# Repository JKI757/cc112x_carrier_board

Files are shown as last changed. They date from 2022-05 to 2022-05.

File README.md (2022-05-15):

## About the Project

- This project is a simple PCB for a carrier board for a a Texas Instruments [CC112X EMK](https://www.ti.com/tool/CC1120EMK-420-470) development board and an STM32 Black Pill board, interface between the two, and jumper set to jump out the STM32 and attach an external microcontroller if necessary.

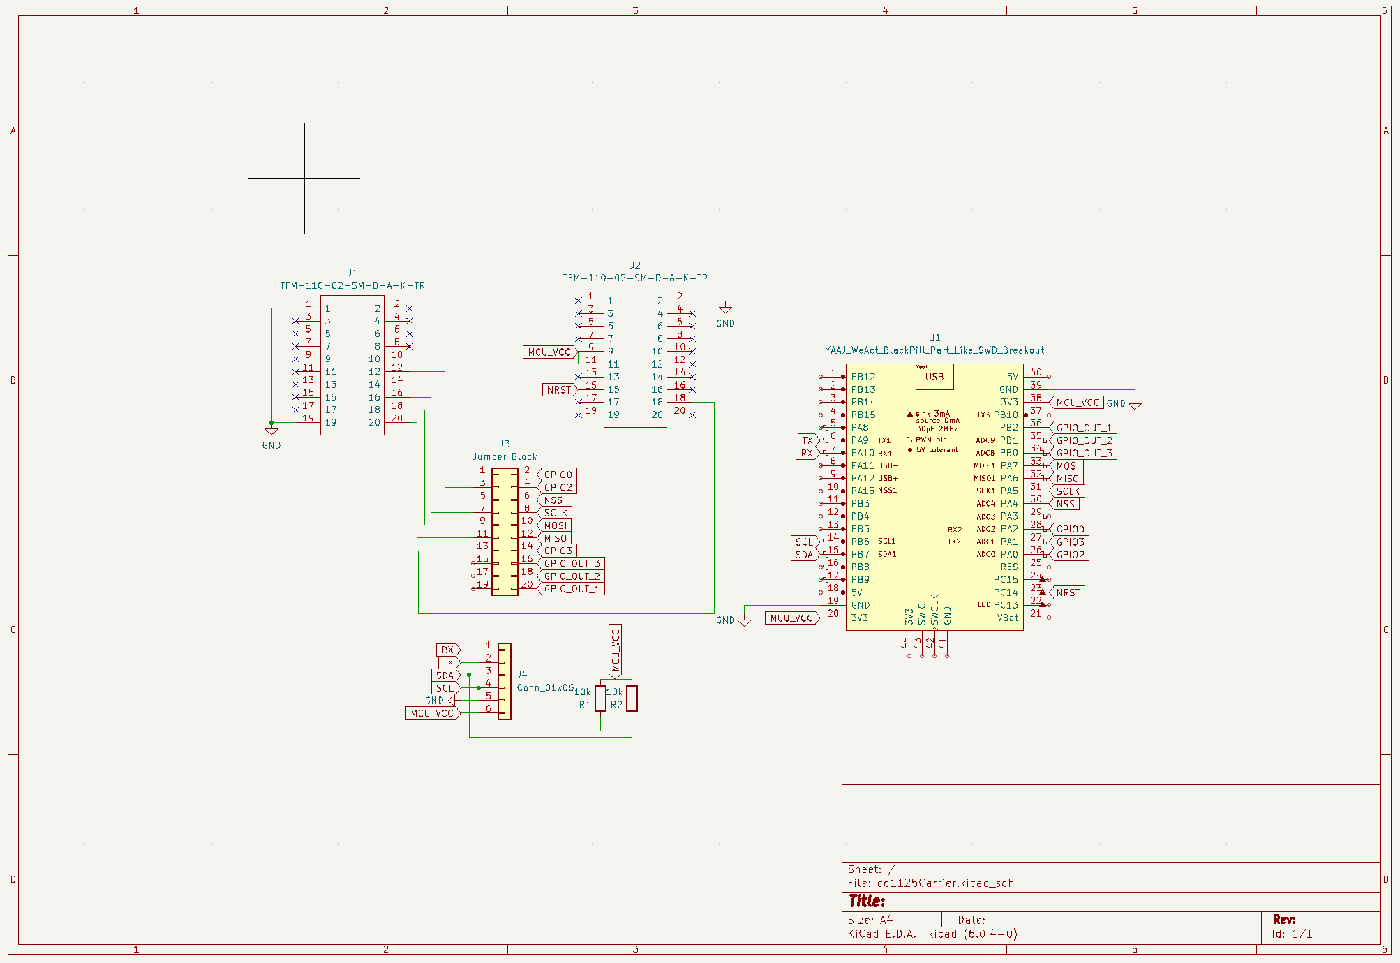
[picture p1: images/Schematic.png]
Schematic


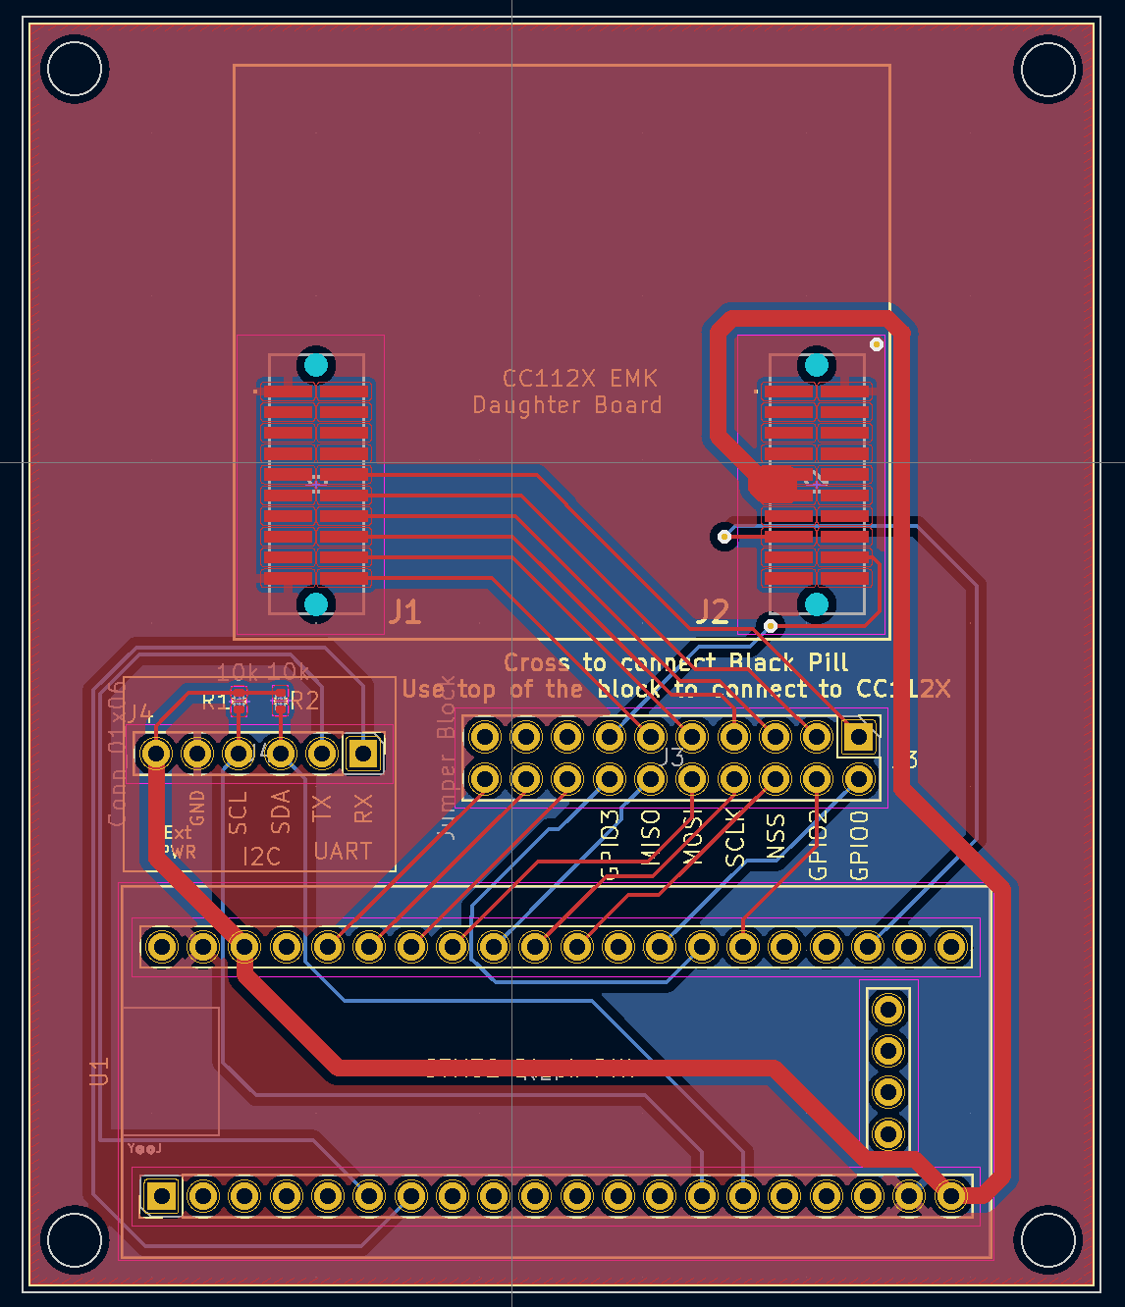
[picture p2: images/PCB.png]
PCB


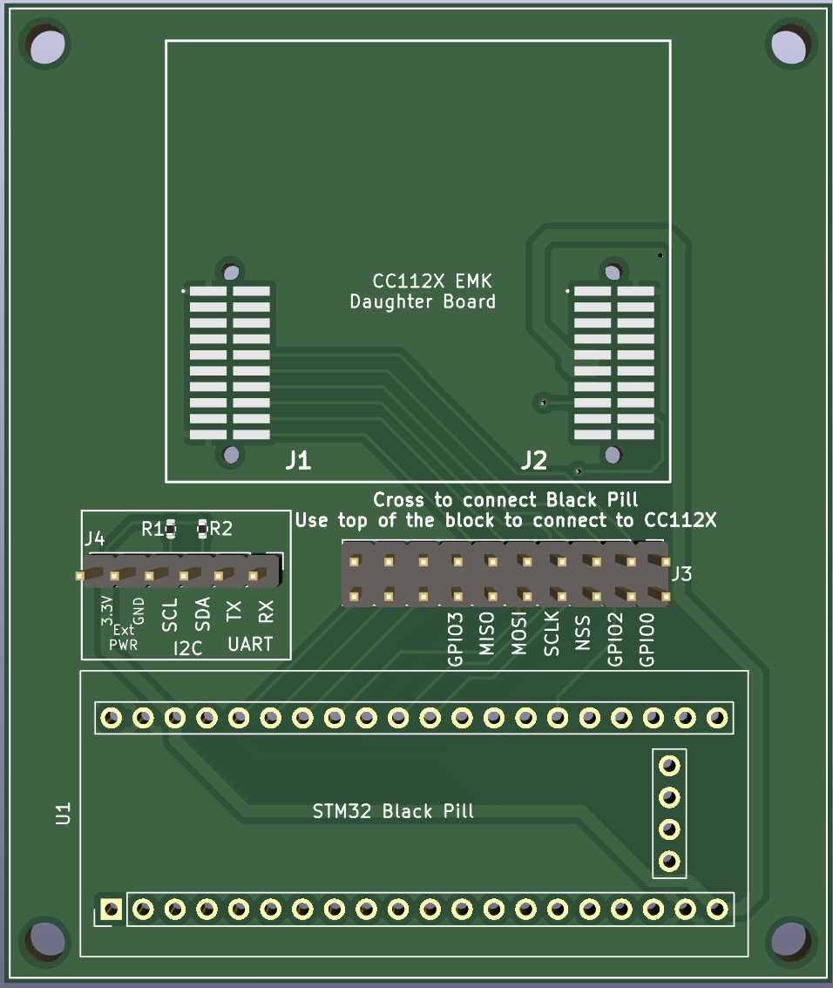
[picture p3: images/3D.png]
3D 3D View


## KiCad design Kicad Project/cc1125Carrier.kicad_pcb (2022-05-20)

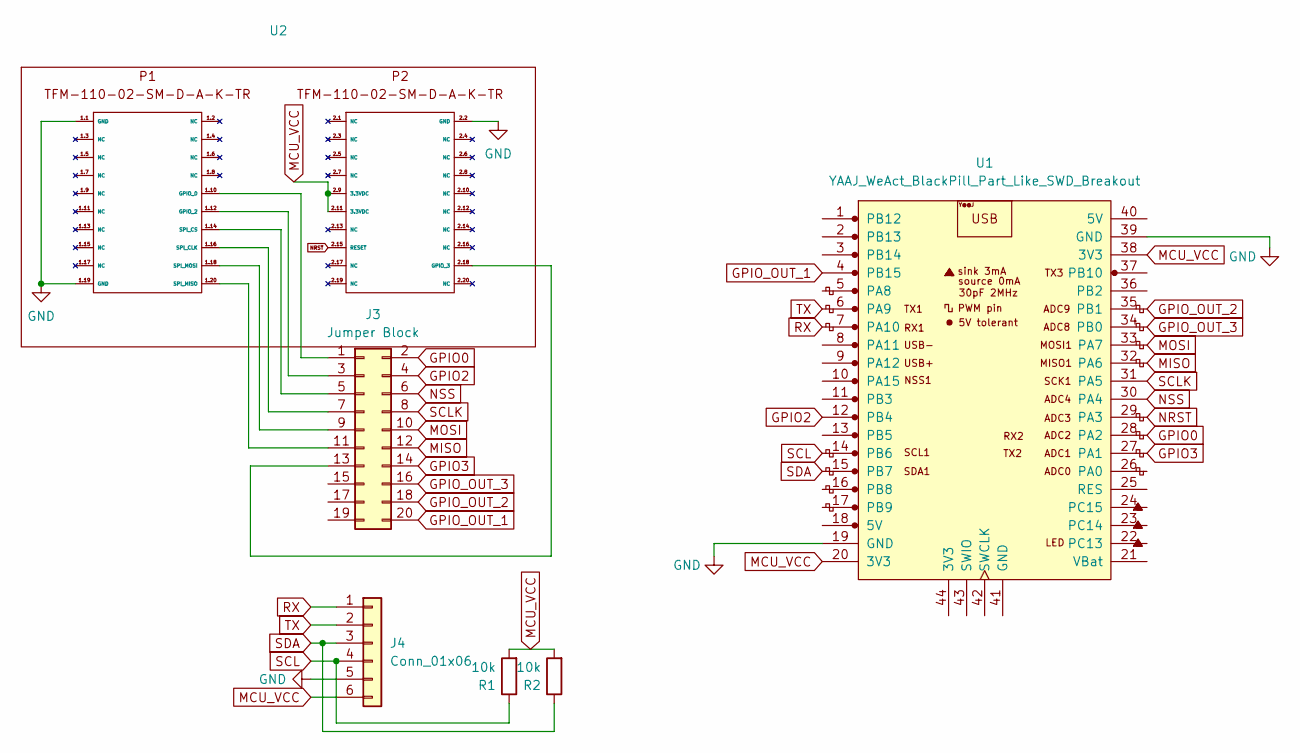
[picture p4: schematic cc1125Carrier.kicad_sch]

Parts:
J3: Jumper Block; PinHeader_2x10_P2.54mm_Vertical
J4: Conn_01x06; PinHeader_1x06_P2.54mm_Vertical
R1, R2: 10k; R_0402_1005Metric
U1: YAAJ_WeAct_BlackPill_Part_Like_SWD_Breakout; YAAJ_WeAct_BlackPill_SWD_2
U2: (no value)

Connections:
GND: J4.5, U1.19 (GND), U1.39 (GND), U2.1.1 (GND), U2.1.19 (GND), U2.2.2 (GND)
GPIO0: J3.2, U1.28 (PA2)
GPIO2: J3.4, U1.12 (PB4)
GPIO3: J3.14, U1.27 (PA1)
GPIO_OUT_1: J3.20, U1.4 (PB15)
GPIO_OUT_2: J3.18, U1.35 (PB1)
GPIO_OUT_3: J3.16, U1.34 (PB0)
MCU_VCC: J4.6, R1.2, R2.2, U1.20 (3V3), U1.38 (3V3), U2.2.9 (3.3VDC), U2.2.11 (3.3VDC)
MISO: J3.12, U1.32 (PA6)
MOSI: J3.10, U1.33 (PA7)
NRST: U1.29 (PA3), U2.2.15 (RESET)
NSS: J3.6, U1.30 (PA4)
unnamed: J3.1, U2.1.10 (GPIO_0)
unnamed: J3.3, U2.1.12 (GPIO_2)
unnamed: J3.5, U2.1.14 (SPI_CS)
unnamed: J3.7, U2.1.16 (SPI_CLK)
unnamed: J3.9, U2.1.18 (SPI_MOSI)
unnamed: J3.11, U2.1.20 (SPI_MISO)
unnamed: J3.13, U2.2.18 (GPIO_3)
RX: J4.1, U1.7 (PA10)
SCL: J4.4, R1.1, U1.14 (PB6)
SCLK: J3.8, U1.31 (PA5)
SDA: J4.3, R2.1, U1.15 (PB7)
TX: J4.2, U1.6 (PA9)

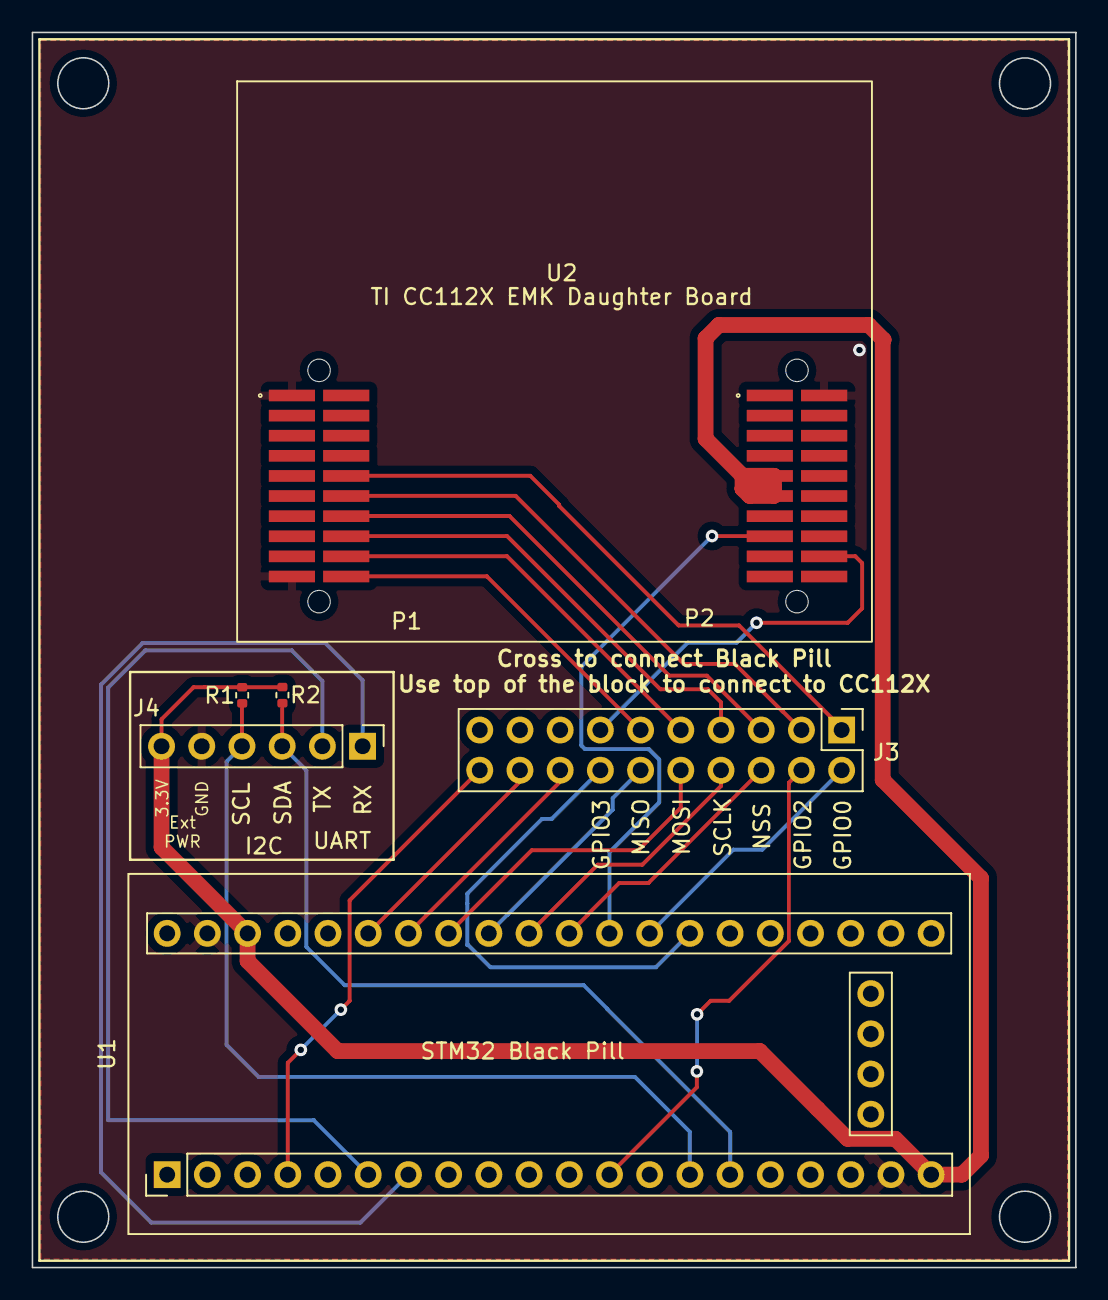
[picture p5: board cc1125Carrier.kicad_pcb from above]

Board: 2 copper layers, 65.9 x 78.0 mm, 6 parts (0 on the bottom side), 24 nets.

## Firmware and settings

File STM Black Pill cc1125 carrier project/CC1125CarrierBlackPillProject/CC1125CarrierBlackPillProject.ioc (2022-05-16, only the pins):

Mcu.UserName=STM32F411CEUx
PA0-WKUP.GPIO_Label=BOARD_KEY_SWITCH
PA0-WKUP.Signal=GPXTI0
PA1.GPIO_Label=TI_GPIO_3
PA1.Signal=GPXTI1
PA10.Signal=USART1_RX
PA11.Signal=USB_OTG_FS_DM
PA12.Signal=USB_OTG_FS_DP
PA2.GPIO_Label=TI_GPIO_0
PA2.Signal=GPXTI2
PA3.GPIO_Label=TI_RESET
PA3.Signal=GPIO_Output
PA4.Signal=SPI1_NSS
PA5.Signal=SPI1_SCK
PA6.Signal=SPI1_MISO
PA7.Signal=SPI1_MOSI
PA9.Signal=USART1_TX
PB0.GPIO_Label=GPIO_OUT_3
PB0.Signal=GPIO_Output
PB1.GPIO_Label=GPIO_OUT_2
PB1.Signal=GPIO_Output
PB15.GPIO_Label=GPIO_OUT_1
PB15.Signal=GPIO_Output
PB4.GPIO_Label=TI_GPIO_2
PB4.Signal=GPXTI4
PB6.Signal=I2C1_SCL
PB7.Signal=I2C1_SDA
PC13-ANTI_TAMP.GPIO_Label=BoardLED
PC13-ANTI_TAMP.Signal=GPIO_Output
PC14-OSC32_IN.Signal=RCC_OSC32_IN
PC15-OSC32_OUT.Signal=RCC_OSC32_OUT

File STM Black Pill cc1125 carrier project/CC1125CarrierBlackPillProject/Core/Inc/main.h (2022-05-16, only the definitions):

#define BoardLED_Pin LL_GPIO_PIN_13
#define BoardLED_GPIO_Port GPIOC
#define BOARD_KEY_SWITCH_Pin LL_GPIO_PIN_0
#define BOARD_KEY_SWITCH_GPIO_Port GPIOA
#define TI_GPIO_3_Pin LL_GPIO_PIN_1
#define TI_GPIO_3_GPIO_Port GPIOA
#define TI_GPIO_3_EXTI_IRQn EXTI1_IRQn
#define TI_GPIO_0_Pin LL_GPIO_PIN_2
#define TI_GPIO_0_GPIO_Port GPIOA
#define TI_GPIO_0_EXTI_IRQn EXTI2_IRQn
#define TI_RESET_Pin LL_GPIO_PIN_3
#define TI_RESET_GPIO_Port GPIOA
#define GPIO_OUT_3_Pin LL_GPIO_PIN_0
#define GPIO_OUT_3_GPIO_Port GPIOB
#define GPIO_OUT_2_Pin LL_GPIO_PIN_1
#define GPIO_OUT_2_GPIO_Port GPIOB
#define GPIO_OUT_1_Pin LL_GPIO_PIN_15
#define GPIO_OUT_1_GPIO_Port GPIOB
#define TI_GPIO_2_Pin LL_GPIO_PIN_4
#define TI_GPIO_2_GPIO_Port GPIOB

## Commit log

2022-05-14 first commit, passes all DRC
    [cc1125Carrier.kicad_pcb, cc1125Carrier.kicad_sch]
2022-05-14 update pullups on i2c, update images
    [cc1125Carrier.kicad_pcb, cc1125Carrier.kicad_sch]
2022-05-15 minor board tweaks
    [cc1125Carrier.kicad_pcb]
2022-05-15 add STM project & re-arrange to include it
    [cc1125Carrier.kicad_pcb, cc1125Carrier.kicad_sch]
2022-05-15 move signals off of PA0 and PB2 due to conflict with stm32 buttons
    [cc1125Carrier.kicad_pcb, cc1125Carrier.kicad_sch]
2022-05-16 add STM32 Board LED & STM32 Board Key Switch
2022-05-20 tweak cc1125 footprint
    [cc1125Carrier.kicad_pcb]
2022-05-20 add emk daughter board symbol and footprint
    [cc1125Carrier.kicad_pcb, cc1125Carrier.kicad_sch]

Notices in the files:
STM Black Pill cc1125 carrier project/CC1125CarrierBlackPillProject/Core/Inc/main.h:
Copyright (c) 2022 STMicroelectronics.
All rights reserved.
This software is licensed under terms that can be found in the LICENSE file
